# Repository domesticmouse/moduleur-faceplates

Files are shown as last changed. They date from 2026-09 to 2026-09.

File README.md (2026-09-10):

# Moduleur Faceplates

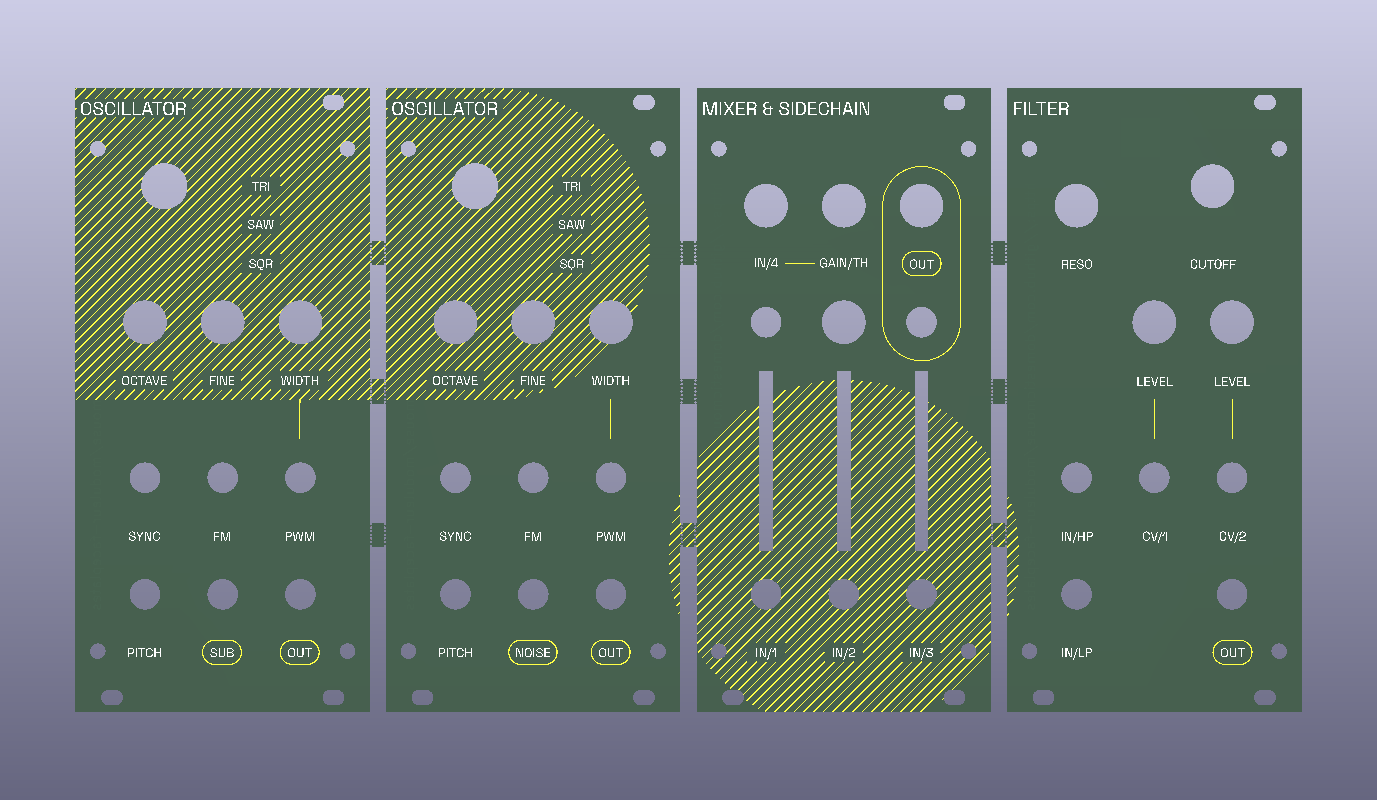
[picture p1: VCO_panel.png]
VCO Panel


Eurorack PCB faceplates and automated panelization tooling for the **[Moduleur](https://github.com/shmoergh/moduleur)** modular synthesizer.

---

## Original Source & Attribution

The mechanical CAD files (DXF) and vector art (SVG) used in this repository originate from the open-source **[Moduleur](https://github.com/shmoergh/moduleur)** synthesizer project created by **[Shmøergh](https://shmoergh.com/)**.

Moduleur is an open-source, fully analog Eurorack modular synthesizer designed to balance the flexibility of modular synthesis with the playability of a cohesive instrument.

- **DXF Cutouts (`DXFs/`):** Define the mechanical hole patterns, Eurorack oval mounting slots, potentiometer cutouts, and 3.5 mm jack placements for the individual modules (`brain`, `vco`, `sidechain-mixer`, `vcf`, `envelope-vca`, and `crush-lfo-output`).
- **SVG Artwork (`SVGs/`):** Provide vector graphics layered across the panels, including front copper, silkscreen, and graphics (`front-copper-clean.svg`, `front-silkscreen-clean.svg`, `front-graphics-clean.svg`, `front-edges-clean.svg`).

---

## Panel Overview

The faceplates are organized into two unified 3U Eurorack panels. Each panel is **48HP** wide (~252.5–252.9 mm × 128.5 mm) and consists of **four 12HP faceplates** arranged side-by-side sharing continuous front artwork:

### 1. VCO Panel (`VCO/`)
Houses the primary audio generation, mixing, and filtering modules (in order, left to right):
1. **VCO** (12HP)
2. **VCO** (12HP)
3. **Mixer and Sidechain** (12HP)
4. **VCF** (12HP)

### 2. VCA Panel (`VCA/`)
Houses the modulation, control, utility, and brain modules (in order, left to right):
1. **VCA and EG** (12HP)
2. **VCA and EG** (12HP)
3. **Utility** (12HP)
4. **Brain** (12HP)

### Directory Contents
For each panel directory (`VCO/` and `VCA/`):
- `<Name>.kicad_pcb`: The source KiCad 10 PCB layout containing the four individual board outlines and continuous artwork.
- `<Name>_panel.kicad_pcb`: The generated panelized PCB joined with mousebites across the inter-board seams.
- `jlcpcb/`: Production-ready fabrication files including Gerber archives (`GERBER-<Name>_panel.zip`), drill maps, and component placement files formatted for JLCPCB manufacturing.

---

## The Panelization Skill

The repository includes a custom agent skill located in [`.agents/skills/panelize/`](.agents/skills/panelize/SKILL.md) backed by the script [`scripts/panelize.py`](.agents/skills/panelize/scripts/panelize.py).

### Design & Architecture

Standard PCB panelizers usually require surrounding frame rails or separate rectangular board copies. Eurorack faceplates, however, present unique constraints:
- **No Outer Rails:** Faceplates must maintain exact Eurorack outer dimensions (128.5 mm height, 48HP width) to minimize raw PCB material costs and avoid rail-removal post-processing.
- **Continuous Artwork:** Graphical artwork, copper fills, and silkscreen often cross board boundaries. Standard panel extraction can accidentally clip elements that extend slightly beyond the `Edge.Cuts` boundary.
- **Burr-Free Edges:** When breaking boards apart after fabrication, mousebite breakout tabs often leave rough burrs. If tabs break on the outer perimeter, the module might not fit flush into a Eurorack rack case.

The skill solves these challenges using **[KiKit](https://yaqwsx.github.io/KiKit/)**, **[Shapely](https://shapely.readthedocs.io/)**, and **KiCad's `pcbnew` Python API**:

1. **Interpreter Isolation via `uv`:** On macOS, KiCad's C++ Python module (`pcbnew`) requires KiCad's bundled Python 3.9 runtime. The script declares dependencies (`kikit>=1.6.0`, `shapely>=2.0.0`) via [PEP 723](https://peps.python.org/pep-0723/) inline script metadata, allowing `uv run` to execute directly with KiCad's Python interpreter without polluting system environments.
2. **Automatic Artwork Bounds Inspection:** Before panelization, the script calculates the bounding box of all graphical drawings on the board. If artwork overflows `Edge.Cuts`, it expands the source extraction tolerance buffer so that continuous graphics are fully preserved.
3. **Sub-Board Detection:** Discovers individual faceplate polygons along the X-axis and calculates exact gap seam dimensions between boards.
4. **Selective Substrate Bridging:** Bridges each inter-board gap with rectangular tabs at designated Y positions (defaulting to **34.0 mm, 62.5 mm, and 92.0 mm**), safely clear of Eurorack oval mounting slots and component drill holes.
5. **Recessed Mousebites:** Directional line vectors (`LineString`) orient KiKit's mousebite perforation cuts so that drill holes are recessed by `0.25 mm` into the waste tab. When broken apart, any remaining burrs remain within the seam space rather than protruding beyond the faceplate edge.
6. **Substrate Validation:** Automatically reloads the resulting board to verify that `Substrate.isSinglePiece()` passes.

### Usage

Run the panelizer using [`uv`](https://docs.astral.sh/uv/) and KiCad's bundled Python:

```bash
uv run --python /Applications/KiCad/KiCad.app/Contents/Frameworks/Python.framework/Versions/3.9/bin/python3 \
  .agents/skills/panelize/scripts/panelize.py -i <path/to/board.kicad_pcb>
```

#### Example: Panelizing VCA and VCO

```bash
# Panelize the VCA layout
uv run --python /Applications/KiCad/KiCad.app/Contents/Frameworks/Python.framework/Versions/3.9/bin/python3 \
  .agents/skills/panelize/scripts/panelize.py -i VCA/VCA.kicad_pcb

# Panelize the VCO layout
uv run --python /Applications/KiCad/KiCad.app/Contents/Frameworks/Python.framework/Versions/3.9/bin/python3 \
  .agents/skills/panelize/scripts/panelize.py -i VCO/VCO.kicad_pcb
```

#### CLI Options

| Option | Default | Description |
| :--- | :--- | :--- |
| `-i`, `--input` | `VCO/VCO.kicad_pcb` | Path to source KiCad PCB layout |
| `-o`, `--output` | `<dir>/<stem>_panel.kicad_pcb` | Output path for panelized PCB layout |
| `--tab-width` | `5.0` | Width of each break-off tab (mm) |
| `--tab-positions` | `34.0 62.5 92.0` | Vertical Y-coordinates (mm from top edge) for bridge tabs |
| `--hole-diameter` | `0.5` | Drill hole diameter for mousebite perforations (mm) |
| `--hole-spacing` | `0.75` | Center-to-center pitch of mousebite holes (mm) |
| `--mousebite-offset` | `0.25` | Inset offset into tab to prevent protruding burrs (mm) |
| `--tolerance` | `None` (auto) | Extraction tolerance in mm for artwork extending beyond board edges |

---

## Repository Structure

```
.
├── .agents/
│   └── skills/
│       └── panelize/           # Custom agent skill definition & scripts
│           ├── SKILL.md
│           └── scripts/
│               └── panelize.py
├── DXFs/                       # Mechanical DXF cutouts from Moduleur
├── SVGs/                       # Front panel vector artwork layers
├── VCA/                        # VCA 48HP panel KiCad project & manufacturing files
│   ├── VCA.kicad_pcb
│   ├── VCA_panel.kicad_pcb
│   └── jlcpcb/
├── VCO/                        # VCO 48HP panel KiCad project & manufacturing files
│   ├── VCO.kicad_pcb
│   ├── VCO_panel.kicad_pcb
│   └── jlcpcb/
├── LICENSE
└── README.md
```

---

## License

This project incorporates assets from the [Moduleur](https://github.com/shmoergh/moduleur) project. As such, the hardware follows the same license as that project.
The licensing is as follows:

- **Hardware & Faceplate Designs:** [Creative Commons Attribution-NonCommercial 4.0 International (CC BY-NC 4.0)](https://creativecommons.org/licenses/by-nc/4.0/)
- **Software & Tooling:** [Apache License, Version 2.0](https://www.apache.org/licenses/LICENSE-2.0)

See [LICENSE](LICENSE) for full terms.

---

## Disclaimer

This is not an officially supported Google product.

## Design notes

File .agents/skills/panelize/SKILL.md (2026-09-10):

---
name: panelize
description: >-
  Panelizes multi-board Eurorack faceplates into unified manufacturing panels joined
  by mousebite break-off tabs using KiKit and KiCad. Use when panelizing KiCad PCB
  layouts, generating Eurorack faceplate panels, or adding break-away mousebites between boards.
---

# Eurorack Faceplate Panelization

Creates unified manufacturing panels from KiCad PCB layouts containing multiple side-by-side Eurorack faceplates (such as 4× 12HP faceplates sharing continuous graphics) joined by break-off mousebite tabs across vertical seams without outer rails.

## Helper Script

The panelization procedure is implemented in [scripts/panelize.py](./scripts/panelize.py). Dependencies (`kikit>=1.6.0`, `shapely>=2.0.0`) are declared directly via PEP 723 script metadata.

## Environment & Prerequisites

KiCad's C++ `pcbnew` module on macOS requires running with KiCad's bundled Python interpreter (typically Python 3.9) rather than system or homebrew Python:

- **KiCad Python:** `/Applications/KiCad/KiCad.app/Contents/Frameworks/Python.framework/Versions/3.9/bin/python3`
- **Runner:** `uv run --python <kicad_python> <script>`

## Running Panelization

### Basic Usage

To panelize a board with auto-derived output name (`<dir>/<stem>_panel.kicad_pcb`):

```bash
uv run --python /Applications/KiCad/KiCad.app/Contents/Frameworks/Python.framework/Versions/3.9/bin/python3 \
  .agents/skills/panelize/scripts/panelize.py -i <path/to/board.kicad_pcb>
```

For example, for the VCA board:

```bash
uv run --python /Applications/KiCad/KiCad.app/Contents/Frameworks/Python.framework/Versions/3.9/bin/python3 \
  .agents/skills/panelize/scripts/panelize.py -i VCA/VCA.kicad_pcb
```

### Options and Customization

```bash
uv run --python /Applications/KiCad/KiCad.app/Contents/Frameworks/Python.framework/Versions/3.9/bin/python3 \
  .agents/skills/panelize/scripts/panelize.py [OPTIONS]
```

| Flag | Default | Description |
| :--- | :--- | :--- |
| `-i`, `--input` | `VCO/VCO.kicad_pcb` | Path to source KiCad PCB layout |
| `-o`, `--output` | `<input_stem>_panel.kicad_pcb` | Path for generated panel PCB |
| `--tab-width` | `5.0` | Width of each mousebite tab in mm |
| `--tab-positions` | `34.0 62.5 92.0` | Vertical Y positions (mm from top edge) for tabs |
| `--hole-diameter` | `0.5` | Drill diameter for mousebites in mm |
| `--hole-spacing` | `0.75` | Hole center-to-center pitch in mm |
| `--mousebite-offset` | `0.25` | Mousebite offset into tab in mm (recesses burrs) |
| `--tolerance` | `None` (auto) | Source extraction tolerance in mm (auto-detects overflowing artwork) |

## How It Works

1. **Artwork Bounds Inspection**: Automatically detects if background silkscreen, copper fills, or drawings extend outside `Edge.Cuts` and expands the source extraction bounding box so full-panel artwork is not clipped.
2. **Sub-Board Detection**: Discovers individual board outlines from `Edge.Cuts` substrates and measures inter-board gap seams.
3. **Tab Substrate Union**: Bridges each inter-board seam with substrate rectangles across the gaps at the designated Y coordinates.
4. **Mousebites Rendering**: Places perforated drill holes along both edges of each tab, offset into the waste material by `mousebite_offset` so edge burrs after breakout do not protrude past the board edge.
5. **Substrate Validation**: Reloads the generated PCB to verify that `Substrate.isSinglePiece()` is `True` and reports final panel dimensions and drill hole count.

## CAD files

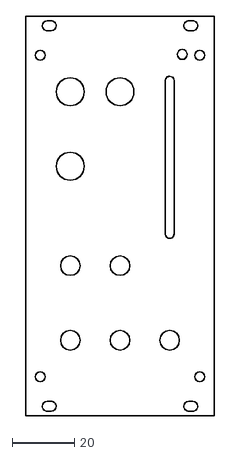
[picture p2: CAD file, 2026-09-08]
DXFs/eurorack-panel-shmoergh-moduleur-envelope-vca.dxf
60.6 x 128.5

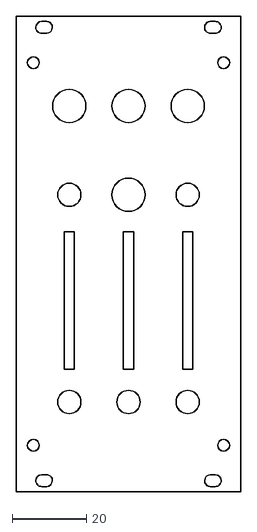
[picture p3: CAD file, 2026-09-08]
DXFs/eurorack-panel-shmoergh-moduleur-sidechain-mixer.dxf
60.6 x 128.5

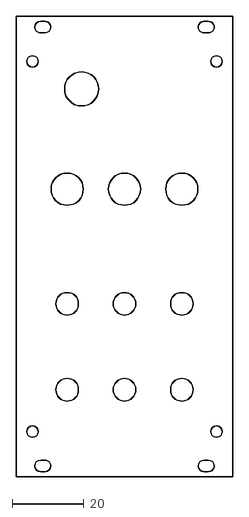
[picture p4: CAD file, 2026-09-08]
DXFs/eurorack-panel-shmoergh-moduleur-vco.dxf
60.6 x 128.5

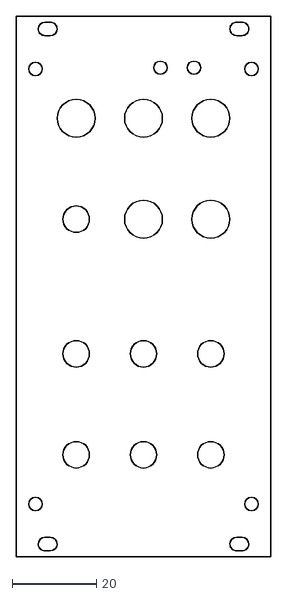
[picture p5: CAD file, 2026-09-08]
DXFs/eurorack-panel-shmoergh-moduleur-crush-lfo-output.dxf
60.6 x 128.5

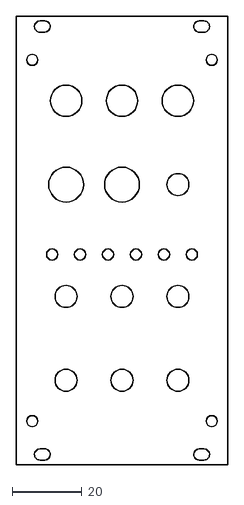
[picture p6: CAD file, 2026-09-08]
DXFs/eurorack-panel-shmoergh-moduleur-brain.dxf
60.6 x 128.5

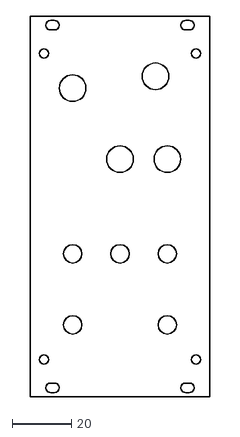
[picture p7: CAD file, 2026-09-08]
DXFs/eurorack-panel-shmoergh-moduleur-vcf.dxf
60.6 x 128.5

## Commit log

2026-09-08 VCO WIP
    [VCO.kicad_pcb]
2026-09-09 Multiple boards
    [BOM-VCO.csv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]
2026-09-09 First pass at panelization
    [VCO_panel.kicad_pcb]
2026-09-09 Update mousebites
    [VCO_panel.kicad_pcb]
2026-09-09 Add back more of the artwork
    [VCO_panel.kicad_pcb]
2026-09-10 VCO Panelization
    [BOM-VCO_panel.csv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]
2026-09-10 Move DXFs
    [eurorack-panel-shmoergh-moduleur-brain.dxf, eurorack-panel-shmoergh-moduleur-crush-lfo-output.dxf, eurorack-panel-shmoergh-moduleur-envelope-vca.dxf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]
2026-09-10 Move stuff around
    [BOM-VCO.csv, BOM-VCO_panel.csv, VCO.kicad_pcb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]
2026-09-10 rename stuff
    [BOM-VCO.csv, BOM-VCO_panel.csv, VCO.kicad_pcb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]
2026-09-10 First pass at VCA
    [VCA.kicad_pcb, VCA.kicad_sch]
2026-09-10 Panelize VCA
    [VCA_panel.kicad_pcb]
2026-09-10 Rebuild VCO
    [BOM-VCO.csv, BOM-VCO_panel.csv, VCO.kicad_pcb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]
2026-09-10 Panelize VCO
    [VCO.kicad_pcb, VCO.kicad_sch, VCO_panel.kicad_pcb]
2026-09-10 Re-panelize and production files
    [BOM-VCA_panel.csv, BOM-VCO_panel.csv, VCA.kicad_pcb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]
2026-09-10 Rename directory
    [eurorack-panel-shmoergh-moduleur-brain.dxf, eurorack-panel-shmoergh-moduleur-crush-lfo-output.dxf, eurorack-panel-shmoergh-moduleur-envelope-vca.dxf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]
2026-09-10 Add URL and re-panelize
    [VCA.kicad_pcb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]
2026-09-10 Re-panelized after code re-structure
    [VCA_panel.kicad_pcb, VCO_panel.kicad_pcb]
